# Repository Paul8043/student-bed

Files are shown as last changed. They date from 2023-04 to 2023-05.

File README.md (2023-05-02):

# Student-Bed

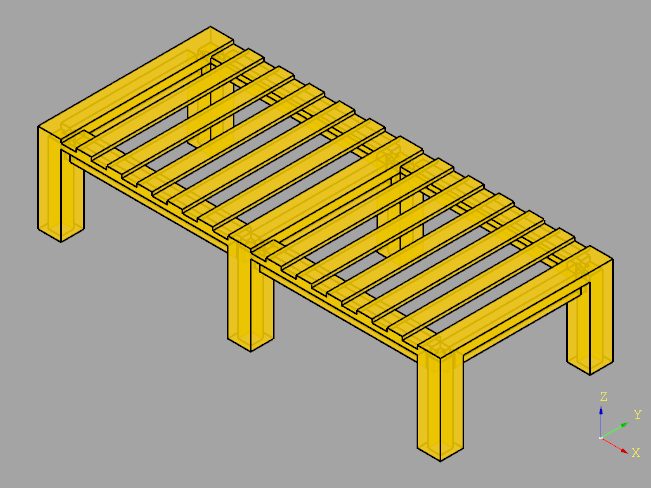
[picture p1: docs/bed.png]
appetizer


# Preamble

Why does this repository exist? My son has declared some demand for an additional bed for his student digs. I have got an order to run a project. That's clear, I take this challenge. This is a perfect candidate to learn Python, Cadquery and some aspects of Woodworking. The entire project is organized as a sequence of mile-stones. After each mile-stone I will add an entry in this Readme.md. Stay curious, I will take you along for a longer, and hopeful, interesting journey. Let us start, the adventure begins ...

# Mile-Stone #1: Model Specification

Before a journey starts, it is always good to know, which destination we want to reach. A clear view of the goal is always helpful. In our case this is a bed, and this bed needs a specification. It comes in two flavors.

The External-Model-Specification, for short EMS, describes the requirements from the view of the customer (my son). Here, he describes what he wants to get. The most important topics are related to measures. All these details can be found in [EMS](docs/EMS.txt). 
 
The Internal-Model-Specification, for short IMS, covers the aspects of the design and implementation. It holds all the details from the view of a cabinetmaker (that's my role). This document can be found here [IMS](docs/IMS.md).

# Mile-Stone #2: Software-Tools 

This project requires some resources for its execution. Some tools are need for the design of the bed, and some others for the wood-working. This project is designed as a tutorial, we try to use the up-to-date tools. Before we do any woodworking, we create a CAD-model first, then we are able to see how it will look like. The tool for this purpose is "CadQuery", a CAD-library written in Python. 

The hidden agenda is to give some stimulus to learn new tools, this applies for us both, for my son and me. Normally 3D-models are drawn by a CAD-Tool. Such tools are powerful, but they require some kind of training. With this project we go in another direction, instead of drawing lines and faces, the 3D-model is programmed, that means we have to write a python-program. This strategy has some advantages, the python-program is very compact and easy to maintain. Changing measures are only a few clicks away.

How does this work? How to convert a python-program to a visual 3D-object? This is the task of a 3D-viewer (renderer), in our case this done by CQ-editor. "CadQuery" and "CQ-Editor" are close companions. In most cases they are used together. As the naming might indicate, the "CQ-editor" can do more than visualizing the model, it has also some capabilities to adapt the python-code. It is a small IDE (Integrated Development Environment). For our purposes this IDE is fully sufficient.
 
As always, a running project is never a straight forward going. It is more an evaluation of various alternatives. Going back and forth is quite normal. What might be the best solution, that will crystallize out later during our journey. Because of that it makes a lot of sense to have good revision-control-system, which can store all intermediate revisions. The top-candidate for this purpose is "git".

And because now-a-days everything can go to a cloud, we establish the infrastructure for this, too. Here we choose GitHub, a platform where you can host your public projects for free. Git and GitHub are also close companions. All code for this project is kept in a folder on the local machine. With some git-commands this folder can be transfered to GitHub and vice versa. In the name-space of GitHub this folder is called a "repository".

There is one thing left over. What kind of editor we will use, for modifying our source-files? We could do this with CQ-Editor, but for this scenario we choose VS-Code. At first glance it looks like an another editor. That's true, but it has many benefits (will become clearer soon).
 
So far, the tool-box for the software-side is almost complete. What is needed for wood-working will be discussed later.

# Mile-Stone #3: Risks with Software Installations

On the windows-platform performing installations is coupled with some risks.

Such a task can be accomplished in a few minutes, if you have good and proven recipe (good luck). If you don't have one, calculate more time, it can consume hours, days, weeks or even more (bad luck).

The standard procedure is:
* go to the web-page of the application
* download the package for your platform (in our case windows)
* read the install-instructions
* run the installer by double-clicking
* answer the questions that the installer might ask

If you fetch the application from an app-store, these steps may run unter the hood. This looks feasible. Normally the installation-instructions are described from the perspective of a blank windows and me-alone-application. But this is an unusual case!

Scenario 1: blank windows + me alone + defaults only (no risk)

This is easy doing. Do not expect any problems.

Scenario 2: blank windows + me alone + defaults changed (low to medium risk)

The installer might ask several questions. Sometimes it is difficult to give initially the right answer, because it is not clear what kind of consequences are associated with your choice. Good written applications offer later on the possibility to adjust these parameters. But most applications give you only a single chance, as long as the installer runs. In this case the installation has to be re-run, by calling first the de-installer. In most cases the de-installer does only remove app-code, but not the associated settings. If you try to re-run the app again, very often you see the same trouble as before. You have to consult "stackoverflow" to see whether there is a solution available. The settings can be scattered all over the world. Try to inspect the dot-files inside your home-directory, your AppData-tree, and sometimes the registry needs special care. At any case to get rid of old settings is a challenge for its own.

Scenario 3: updated windows + old-me (low to medium risk)

A lot of applications have a built-in updater. Try to use it as first choice. Your settings will be preserved and only the code gets updated. This has low risk. If you have to de-install first, then the risk will rise up to medium level.

Scenario 4: updated windows + many other apps + me (high risk)

Typically an application does not only depend on windows, but on some other applications. And each application can request specific revisions of other applications. This is really a difficult scenario, which means the applications have to be installed in the right sequence. And sometimes the applications request contradictory revisions.

Scenario 5: broken installation (highest risk)

An installation should always be an all-or-nothing operation, which means an application should succeed or leave the computer untouched. On the windows-platform installations are something in between. This situation can be reached easily, if the installer fails. In this case the application is in a corrupted state. It is like a zombie. You can only recover by applying steamroller tactics which means installing windows from scratch, waiting for days until all window-upates are applied, and installing all other applications again!

To make this long story short: Make sure you have a backup of at least your user-data, or even better, create an image-backup first to preserve your working environment!

# Mile-Stone #4: Software Installation

Our installations belong to scenario 4, which means we are walking in the high risk area.

The following procedure describes the needed steps, assuming that these applications are currently not installed on your computer. If some are already present, you can skip individual steps. But be aware you are entering an unexplored area which may show up new surprises.

Make sure that your windows is up-to-date (windows-update).

We install "git" first. Follow the instructions given [here](docs/HowTo-Git.txt). The video there, is highly recommeded. Don't forget to specify "user.name" and "user.email" at the end of the procedure. Without that "git" will reject to perfom any work for you. If it succeeds, you will have a Git-Bash on your desktop. With this you can open a Command-Shell. It looks similiar like a CMD-window, but is offers much more capabilities. You get full access to "git" and some famous linux tools like "find" and "grep". Always use the Git-Bash, if you plan to talk to "git" from the command-line level. Other Command-Windows like CMD or Power-Shell do not have the right context. Keep that in mind.

Next we take care for GitHub. GitHub promotes "GitHub Desktop". It is not really needed for our initial steps. Do not install it at this point. To use GitHub, you don't need any installations, you need just an account. Perform the steps listed [here](docs/HowTo-GitHub.txt). Then define your first "repository" which consists initially of 3 files: a "Readme.md", "LICENSE" and a ".gitignore". For ".gitignore" select the template for python. The "LICENSE" is up to you. There is one subtlety here: "git" had asked you to specify your email-address and "GitHub" has asked you for a login-name which is likewise also an email-address. Both work only work smoothly together, if the email-address is same for both.

The next application is Visual Studio Code, often simply called VS-Code. Originally it has been designed as an editor. But in the meantime it has reached the level of a comfortable IDE (integrated develop environment). VS-Code has extensions for almost everything. For Python and many other programming languages. Besides this, it offers built-in git-support. By using VS-Code you can do all needed git-tasks thru the graphical interface which is really simple to use. Some more details are given [here](docs/HowTo-VSCode.txt)

The welcome-screen, which pops up during first start-up, recommends some other things to activate. Be reserved and resist the temptation to activate more. If I remember correctly, there was one flag related to git, which I have activated.

You should only install the following extensions for the very beginning:

* Your language Pack
* Git Graph
* Python (by Microsoft)

Now we have reached a stage where we can consider to install CadQuery and CQ-editor, see [here](docs/HowTo-CadQuery.txt) to grasp all the details. And as always, goto the web-page and learn how to install. After you have read the Readme.md, you are overwhelmed by such a variety of choices. And what does fit for my machine? The first answer is, it depends: great! You have come in touch with new tools never heard before. Some phobia came up in my head, because this looks like additional work. There will be more effort needed to get the new serpents, called "conda" and "mamba", under control. They don't have an own home, they reside together in a common refugium called [miniforge](https://github.com/conda-forge/miniforge).

It will take awhile to find out how the things work in this area. You know already, all this stuff belongs somehow to python-installations. A lot of strange things at first glance. The goal is to find a running combination of Python, CadQuery and CQ-Editor. All 3 depend on other packages, and each of them can have additional dependencies. Python has a package-manager called "pip". Why is "pip" not sufficient? And then you remember why some installations are associated with high risks (scenario 4). Because they might have contradictory requirements. Could "conda" and "mamba" be a solution for this problem? We will see it soon. In this context a new term, named "virtual environment", appears on the scene. Unfortunately there exist several flavors of "virtual environments" and which is the right one for my project? Questions over questions. There is no other way as to learn these tools. Thanks to the internet you get access to this information immediately, but it takes time to learn. So, my first model, created by CadQuery, has to wait.

And it would make sense to check how big is already the chaos on my computer? How many different versions of python can I find? A double-click on a python-script opens Thonny. Luckily Thonny comes with a built-in version of python and any pips remain in the conext of Thonny. This is good so far. But I can do "python --version" in various Command-Windows. Some do not see Python at all, some others show older versions. Not so nice! Then I found an old Anaconda installation, which I have removed by calling its de-installer. Thonny, I want to keep. I hope the field is cleared enough and ready for CadQuery.

To make it clear:
* pip is a package-manager only
* conda is a combination of environment-manager and package-manager
* mamba is simply a faster conda

The environment-manager creates the needed virtual-environment. This is some kind of a sand-box for your application and the needed dependencies.

The contours got shaped, the picture is clear enough to start. This means I will continue with "mamba".

Let us try to install mamba. All details are given [here](docs/HowTo-Mamba.txt)

After this little detour we return back to the installation of [CadQuery](docs/HowTo-CadQuery.txt). The installation is more or less a one-liner!

Now it is time for a longer coffee-break!

# Mile-Stone #5: Say Hello

Whenever a new environment has been set up, it is good practice to check, whether all tools are callable. For this purpose we say [hello to python](docs/hello-python.py). This is just an one-liner, a simple print-statement. We try this first on VS-Code. Make sure that the python-extension has been activated, then run the program. In the lower panel there is a tab, named Terminal, where you can find "Hello, Python" among some other text. Now we do the same thing with CQ-Editor. The one-liner appears in the Editior-Panel, but pressing the run-icon does not show any reaction, the console-panel at the bottom remains empty. This is unexpected behavior. Reading again the Readme.md of CQ-Editor reveals the output does not go to the console-panel, but it appears on the shell-window, from where the cq-editor has been started. Not very comfortable, but there is offered a better alternative named log().

Now we say [hello-to-cadquery](docs/hello-cadquery.py). With VS-Code the python-program runs without any complaints, but there is no graphical output. This is expected behavior, because nothing is built in the code to show graphics. Now we try the same thing with CQ-Editor. And oh wonder the model appears on the right upper corner. The CQ-Editor can show models without any lines of code. This is great.

But then why writing a section in the Readme.md which explains how to create graphical output, if it works without? There you can learn, only 2 functions are in charge with graphical output:

* show_object()
* debug()

Uncomment lines #6 to #9 and see what happens. The top-face is colored red, and logger-output appears in the Log-Viewer in the lower-bottom corner. Both functions are only needed, if the graphical output has to be customized in some way. Now we make the cross-check on VS-Code and we see some dark clouds at the horizon, because it reports several errors. VS-Code does not know show_result(), debug() and log().

# Mile-Stone #6: Template for Both

Some stubs are created, so that the python-script can be run without any errors on both editors. The template is given [here](docs/template.py).

# Mile-Stone #7: Recommended Workflow

There are many variants possible. The sequence below is easy to use for newbies.

1) create a repository on GitHub
2) clone it to your local machine
3) take the template from the docs-directory as a skeleton to start with
4) activate environment via mamba
5) start VS-Code & load your folder
6) start CQ-Editor and load your python-program
7) edit & modify your program, SQ-Editor will draw the model after every change
8) commit your changes to git, and optionally to GitHub
9) repeat steps 7 to 8 
10) close CQ-Editor
11) close VS-Code
12) deactivate environment via mamba

If the repository is created first on GitHub, this has the advantage that the relationship between "remote" and "local" is established from the very beginning.

Some additional hints to "git". The git-database, which holds all your revisions, is stored in a hidden folder named ".git" and it is stored in your project-directory. Never touch this folder and its contents, it would lead to a corrupt database, and all your version can disappear. Having ".git" directly under your project-directory implies that when the project-folder is moved, all revisions go along automatically. There is another dot-file, named ".gitignore". It controls which files and sub-folders are put into ".git". Files and sub-folders excluded here, remain untouched by git, they are untracked. These files and folders can resides anywhere in your project-tree. They remain untouched. They will never appear on GitHub. Keep in mind, "git" has been designed for processing text-files, not for binaries. Binaries can be added, but they consume a lot of space. For each change a copy of the binary is added. Because of that do not store large binary files (BLOBs). The repository will grow quickly and uploads & downloads will take very long.

Steps 7 & 8 need some more explanation. "edit" and "save" are clear. Revision-handling with git is a 3-step-approach: 
* add a file, after saving, to the stage-area. A file there is marked with "A".
* make a commit, the contents of the stage-area goes to the ".git"-folder
* press synchronize, this works in both directions, after that the local changes appear on GitHub.

The CQ-Editor is primarily used as a model-viewer. In the View-menu turn off all unwanted panels, except "Log viewer" and "Current traceback". And in the Preference-Section enable "autoreload". This flag is required, otherwise an automated model-refresh does not take place, if the model has been changed with VS-Code.

# Mile-Stone #8: Let the Model grow

The design is kept simple. The duckboard is split into 2 halves (not visible at the moment). In total we need only 4 different parts:
* jambs 
* stringers
* ledgers
* battens

[parts-piled-up](docs/bed-piled-up.jpg)

A jamb has a hollow body. The ribs can be plugged into the slots of the jamb.

[jamb](docs/jamb.png)
[rib](docs/rib.png)

The frame is built with 6 jambs and 7 ribs.

[frame](docs/frame.png)

The duckboard covers only one half of the bed. The battens are simply loaded on top of the stringers and ledgers.

[stringer](docs/stringer.png)
[ledger](docs/ledger.png)
[duckboard](docs/duckboard.png)

Both duckboards are loaded on top of the frame and the bed is ready. Mission complete, at least related to the design.

[bed](docs/bed.png)

# Mile-Stone #9: Prototyp

CAD-Model are great, but the real thing is better. Why not print the model with a 3D-Printer? The jambs can be printed in their original orientation. The ribs are flipped by 90 degrees and the duckboards are printed upside-down.

Simply, puzzle the parts together and the prototype is ready.

[prototype](docs/prototyp.jpg)

# Mile-Stone #10: Storage Check

The bed is demountable. Just open the screws on top of the jambs. All parts can be stacked together. They fit easily in the stoarage area, specified in the [EMS](docs/EMS.txt)).

[parts-stacked](docs/bed-stacked.jpg)

# Mile-Stone #11: Bill Of Material

It is time to order material. The complete list given as CSV-File, see [bom](docs/bom.csv).

# Mile-Stone #12: Generation of SVG-Files

With the 3D-model ready, it should be a simple task to generate the SVG-files. But this was not true.

The generation of SVG-files was more difficult than expected. The original idea was to make some sectional views of the needed parts. My router expects SVG-files and CadQuery can generate SVG-files and many other formats. This works in principle, however there are two limitations:
1) A simple sectional view is not enough for the router. Some helper-lines are needed, which have to be added.
2) CadQuery puts a projection of the 3D-model into the SVG-file.
The projection can be switched off, but the output is scaled to some unknown factor. This ok, if the SVG-file is just used as a viewer, but for my purpose (to control directly the router) this does not fit.

Because of that, the initial idea has been given up. The 2D-drawings are created as additional entities. They are stored in DXF-format. QCAD is used for the post-processing, close polylines, set the map scale to 1:1000 and increase the line width to 0.13mm (ISO) and then do an extended SVG-Export

In total 4 SVG-Files are needed. The jamb is assembled of 2 broad and 2 small sides.

jamb-broad

jamb-small

It is always difficult to drill holes in abutting faces. The jig below helps to do this.

jamb-jig

And the ribs need both-sided notches.

rib-short

# Mile-Stone #13: Implementation

The model does not show all details. The prototype generated by the 3D-printer has some special requirements, and this may deviate from the wooden realization. All the aspects, how the wooden parts are joined together are not covered in the model. These are decisions of the implementation and the issues in this area are described in the [IMS](docs/IMS.md). The bed is a simple construction and therefore the IMS can be kept short. Only a few things need to be discussed there. The frame, consisting of jambs and ribs, does not need any kind of special junction-elements. The notches in the wood are sufficient. For the duckboard it looks different. The bed has to be demountable and because of this some screws are a good and simple solution. I have chosen screws with metrical threads and these screws need a metallic counterpart, called inserts. This gives a very stable junction, which can be easily detached. The leftover is normal wood-working. The focus here is, how the wooden parts can be routed easily. This depends on the equipment, you can use. The drawings for routing are already covered in the previous mile-stone.

After so much work we can have a look at the real bed!

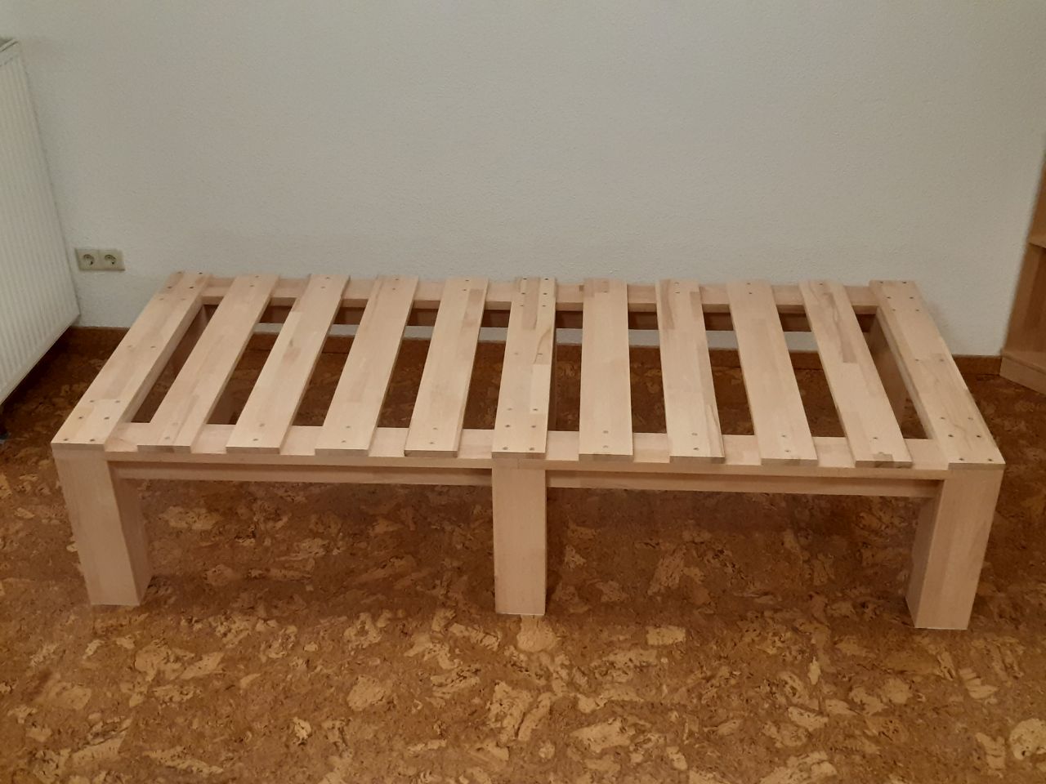
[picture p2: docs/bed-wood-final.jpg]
bed-wood-final


# Mile-Stone #14: Delivery

The delivery has already taken place. The transport was easy and the mounting of the bed was simple, too. The setting-up time was 25 minutes, a few minutes more than expected!

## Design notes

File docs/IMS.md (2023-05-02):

Internal Model Specification

This document describes how the bed is built up. 

The main focus here is how the wooden parts are made and how they are joined together. For the frame the notches serve for this purpose. Jambs and ribs can be simply plugged into each other. For the duckboard it looks different, here the junctions are made with screws. The duckboard consists of two halves. They have to be connected with each other and both with the frame. In the corners the duckboard is bolted with 4 screws. In the middle the duckboard is only bolted with 2 screws. So, the jamb in the middle, with its 4 inserts, is shared by both duckboards and the batten on top belongs to both duckboards. This gives a stable connection and the optical appearance is pleasing.

The bed has to be demountable and because of this woodscrews would be a poor choice, it is much better to use screws with metrical threads. The screws need a metallic counterpart as a nut. But normal nuts would also not be a good choice, better to use inserts, they will remain all the time in the wood, they cannot get lost.

Now, let us go back to the wooden parts. We need pre-cut-plans for all oft them. The dimensions are listed in the [bom](bom.csv).
 
Some wooden parts deviate from the plastic-version of the prototyp. There the jambs are a single box which is shelled out. The wooden-version consists of 2 broad and 2 small sides which are glued together later on. This is mentioned, because the pre-cut-plans show parts which cannot be found in the model.

In our do-it-yourself-stores glued beech wood is offered with thickness of 18mm and 27mm. The format for 18mm is 200cm x 40cm and for 27mm the format is 260cm x 63.5cm. These plates are taken as raw material. The following pre-cut-plans show how the individual parts are cut-out.

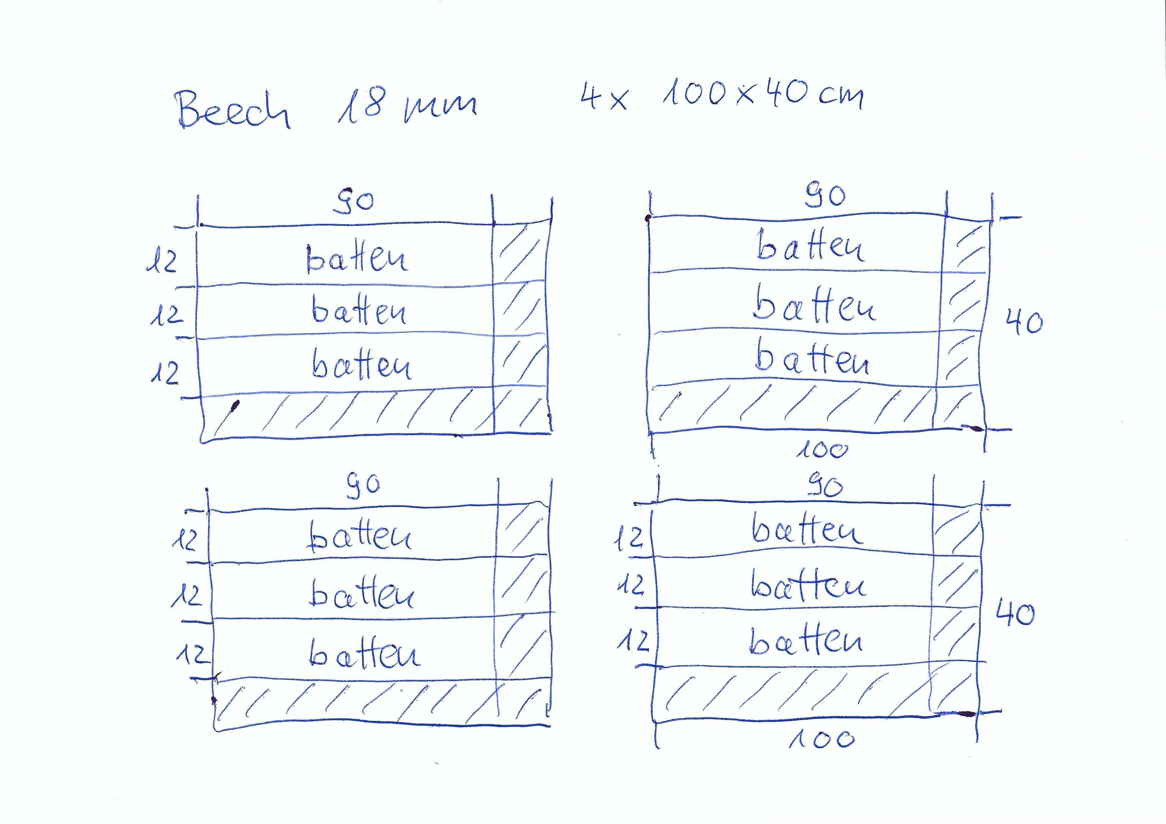
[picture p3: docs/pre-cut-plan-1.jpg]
pre-cut-plan-1


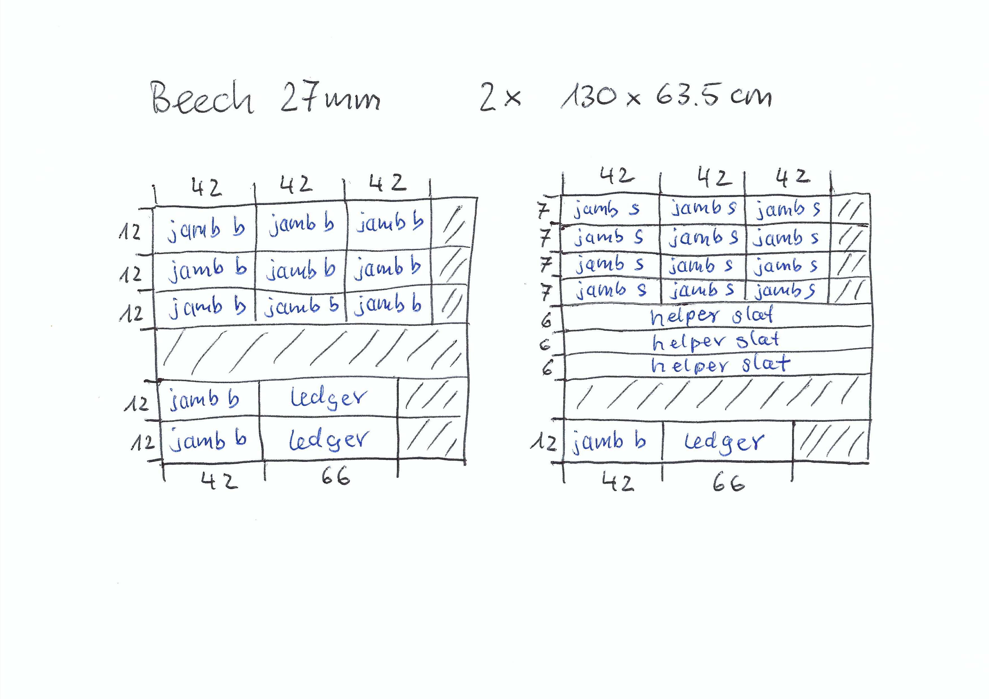
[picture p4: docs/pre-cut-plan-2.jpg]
pre-cut-plan-2


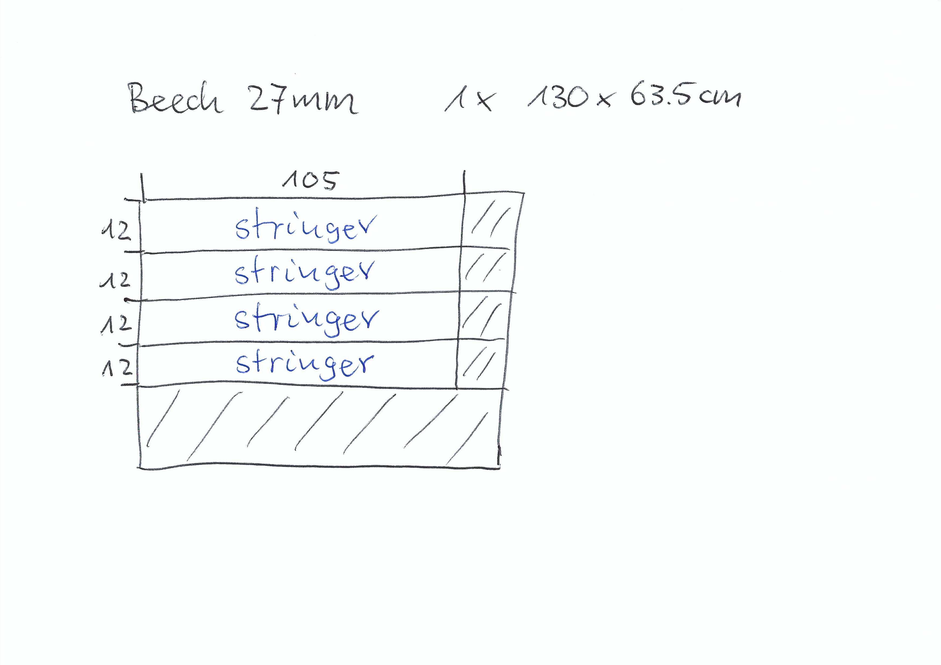
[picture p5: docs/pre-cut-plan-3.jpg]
pre-cut-plan-3


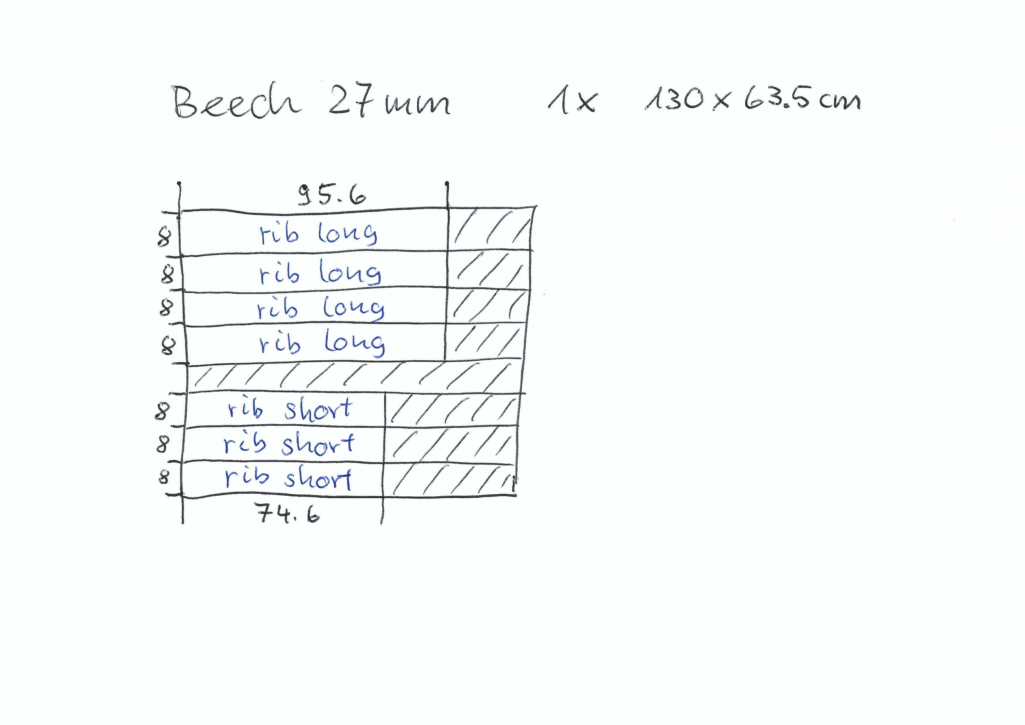
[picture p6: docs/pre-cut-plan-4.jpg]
pre-cut-plan-4


The next step is to make cut-outs of the jamb-plates. This is done with the help of two 2D-drawings:

jamb-broad

jamb-small

The inner rectangle shows the nominal size of the plate. The outer rectangle is 10mm larger on all sides. This helps to mount the plate for the router. The cut-out-area, also a rectangle, is extended by 5mm on the left side. This needed to get a straight line, otherwise the milling-cutter (6mm) would make a fillet.

The jamb, if glued together, looks quite well.

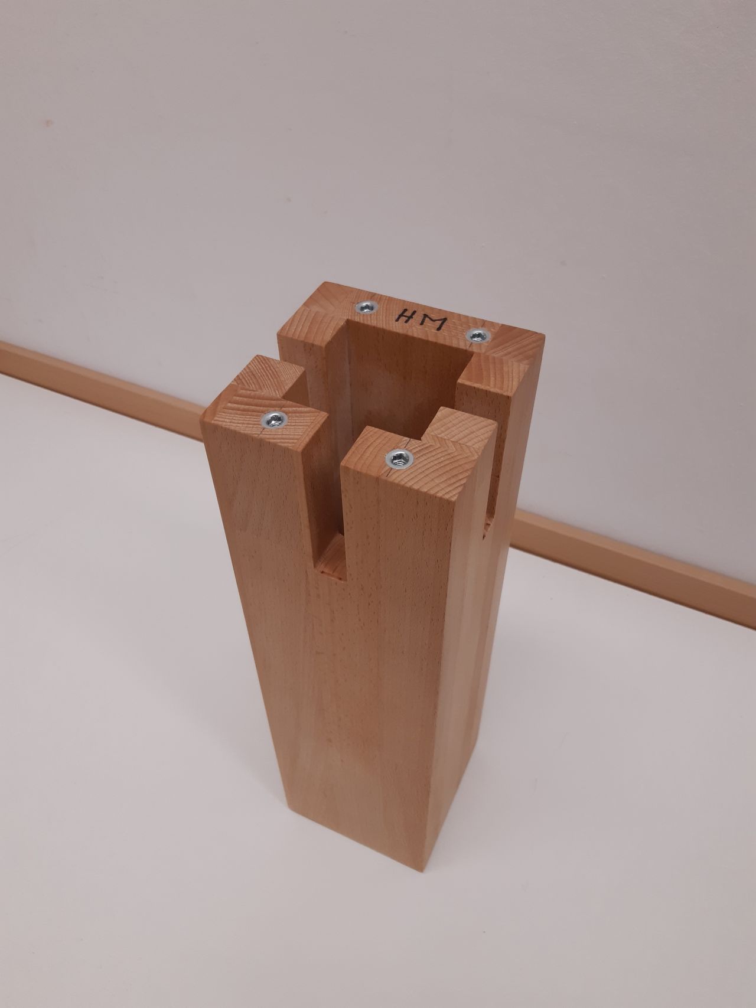
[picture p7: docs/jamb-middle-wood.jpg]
jamb-middle-wood


The drilling of the holes for the inserts is not trivial. They have to be positioned very exactly and the holes have to be perpendicular. The size of the jamb is too large for a standard drilling-machine. There was no other choice as to try a free hand drilling. And, that this will be successful, I made a jig for this purpose. The 2D-drawing for the jig can be seen below.

jamb-jig-qcad

And the wooden version looks this way.

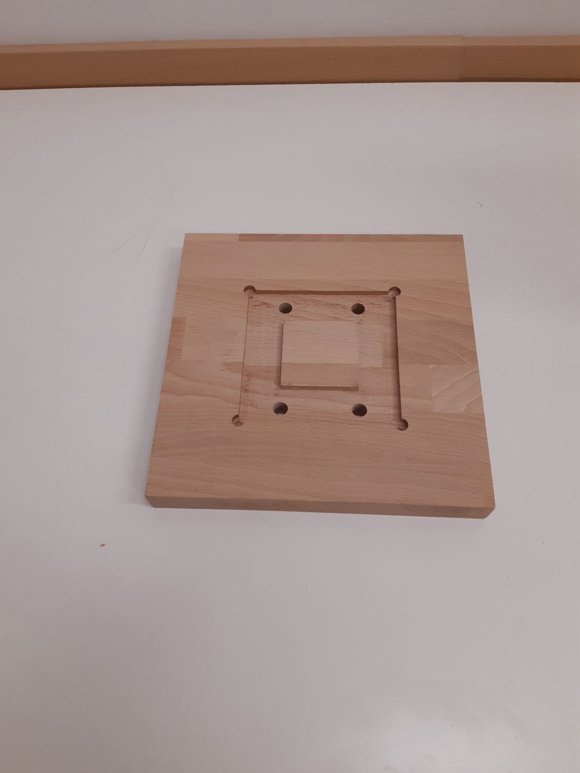
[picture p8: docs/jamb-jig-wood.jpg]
jamb-jig-wood


The jig is simply put on the top of the jamb, but upside down. Then the drill-bit has enough leading and hole is really perpendicular.

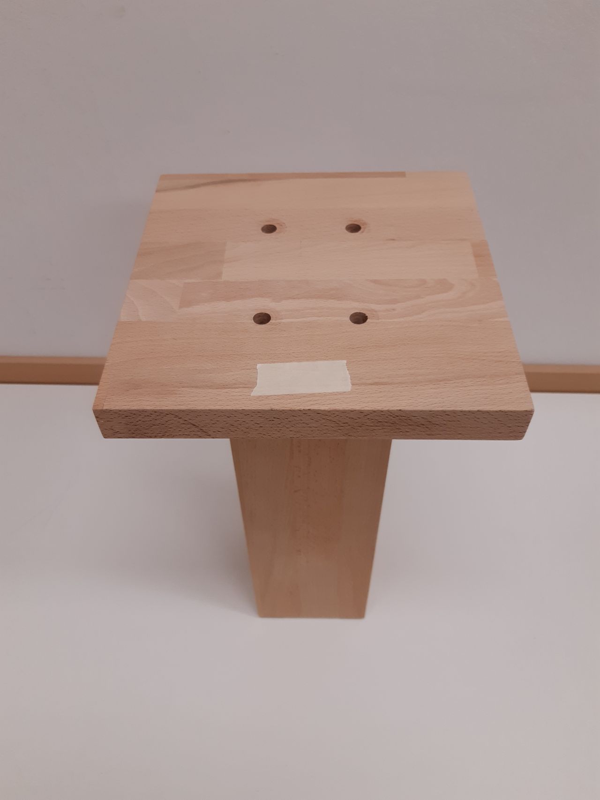
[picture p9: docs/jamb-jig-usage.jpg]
jamb-jig-usage


The holes for the remaining parts are uncritical, the are drilled on a drill press.

And as always, some not planed problems occur. Two of the stringers had ugly knotholes.

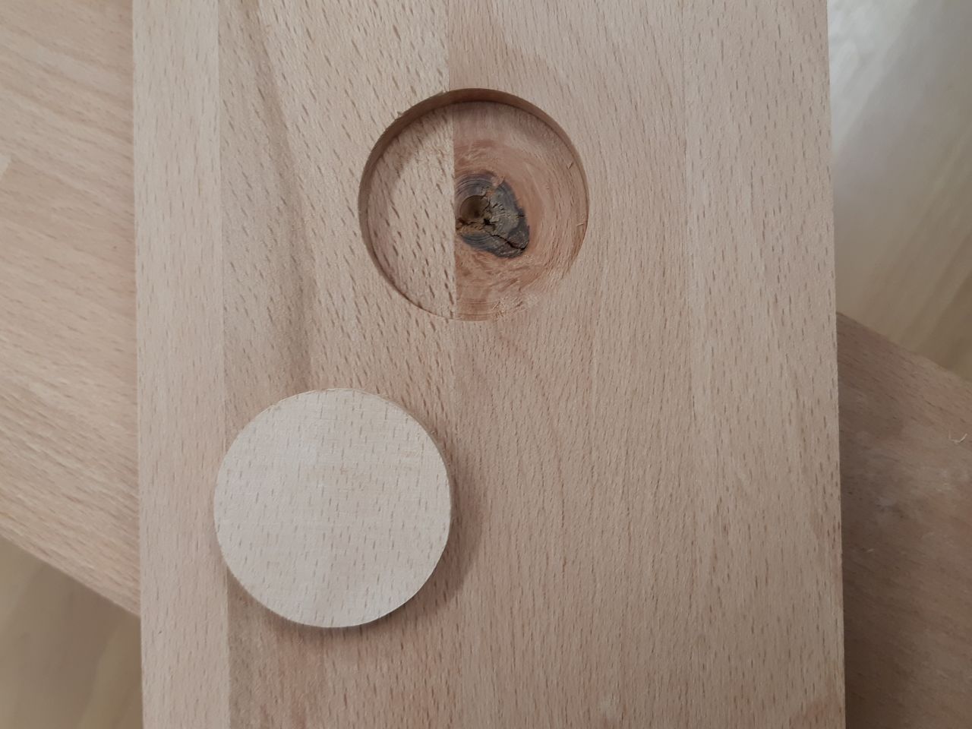
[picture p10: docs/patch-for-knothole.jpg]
knothole


After the repair it looks much better.

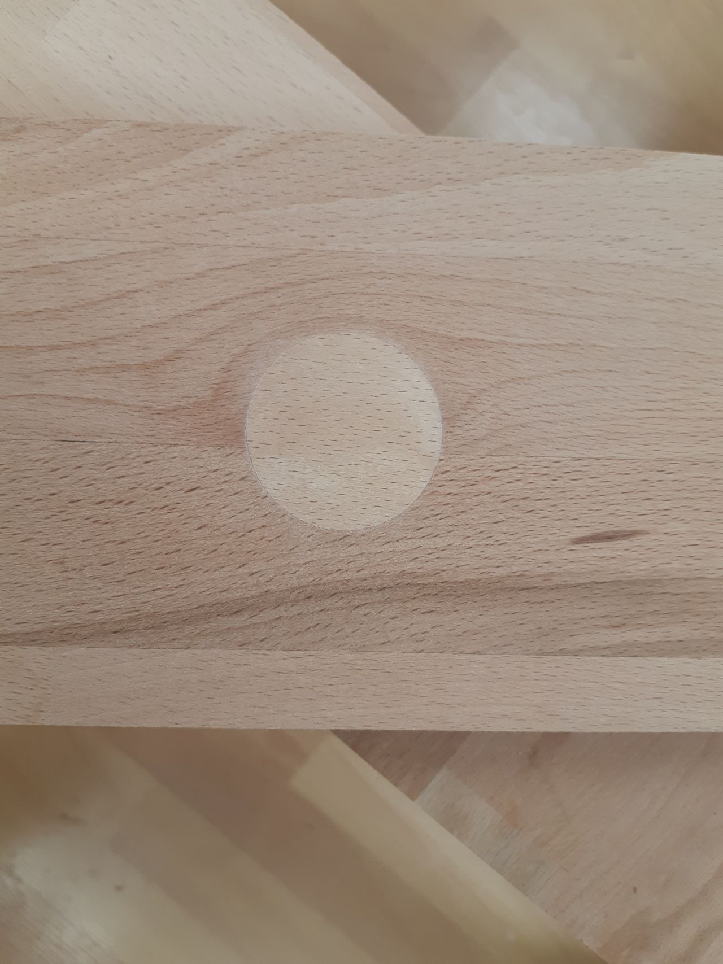
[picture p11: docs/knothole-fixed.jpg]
knothole-fixed


Just for completeness all other wooden parts are listed below.

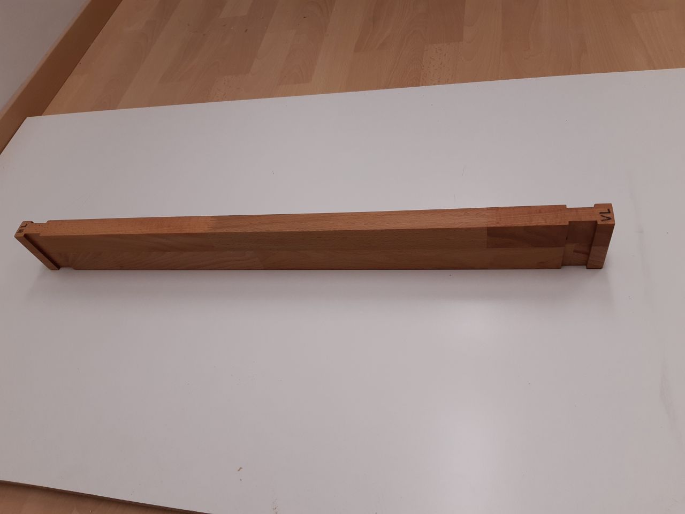
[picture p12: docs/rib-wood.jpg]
rib-wood


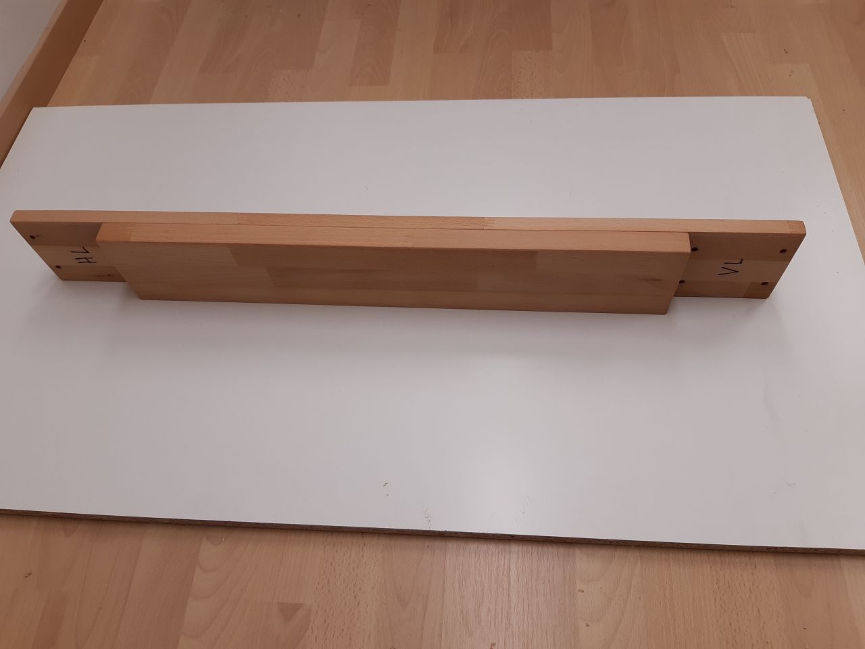
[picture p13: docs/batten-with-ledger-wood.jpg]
batten-wit-ledger-wood


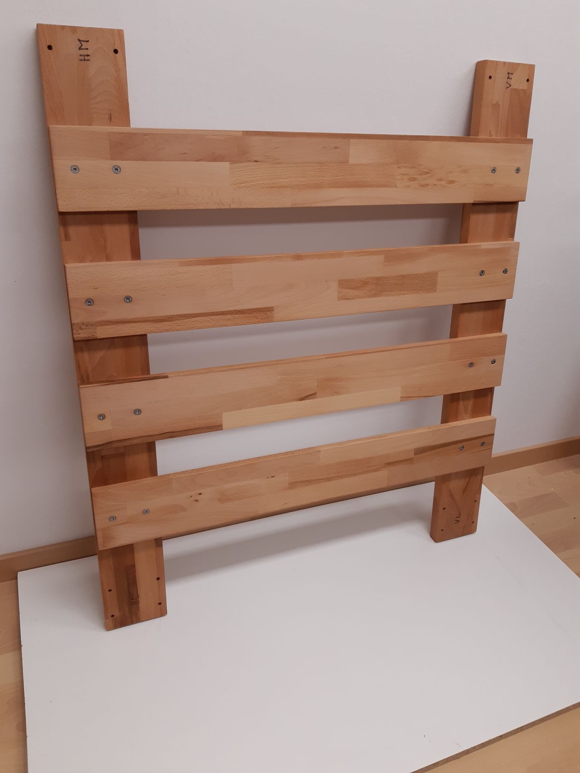
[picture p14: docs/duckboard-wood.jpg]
duckboard-wood


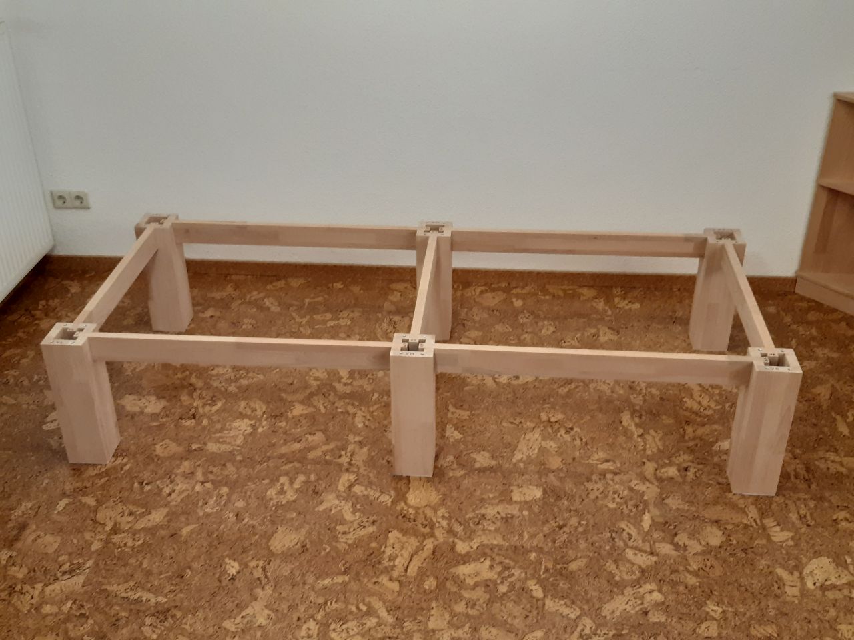
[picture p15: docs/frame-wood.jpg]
frame-wood


And our final result, everything mounted together, looks fine.

bed-wood-final

Mission complete!

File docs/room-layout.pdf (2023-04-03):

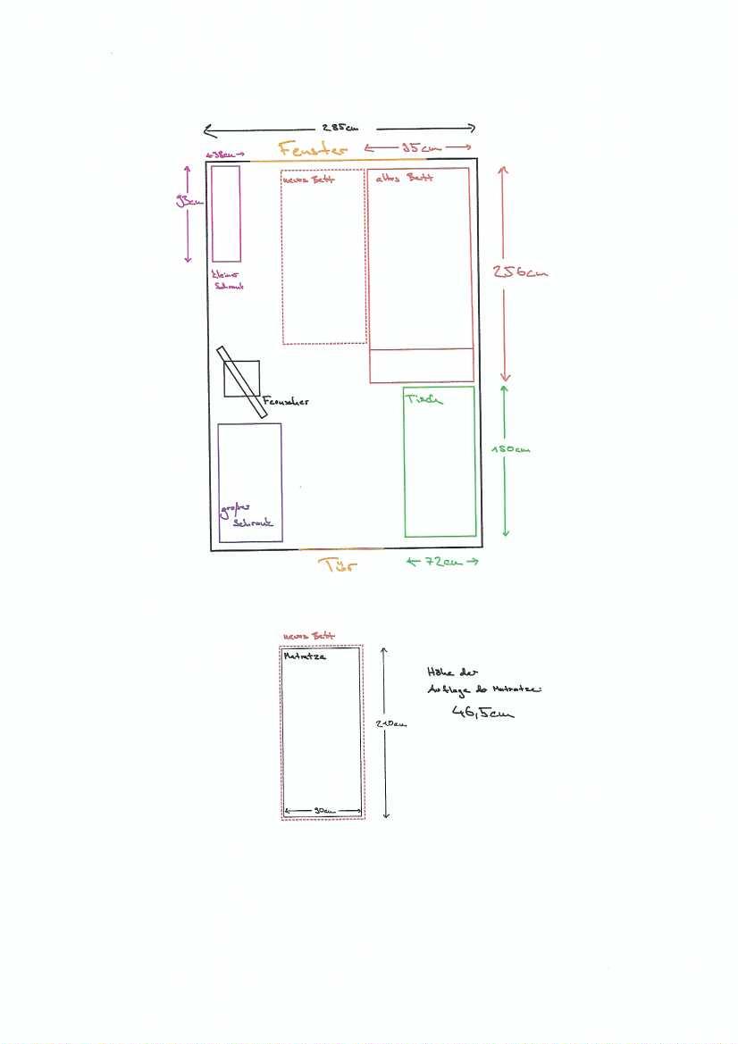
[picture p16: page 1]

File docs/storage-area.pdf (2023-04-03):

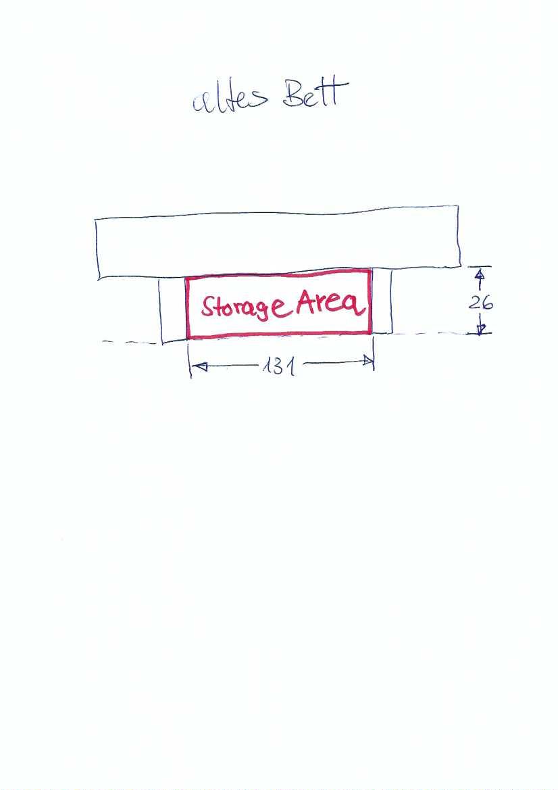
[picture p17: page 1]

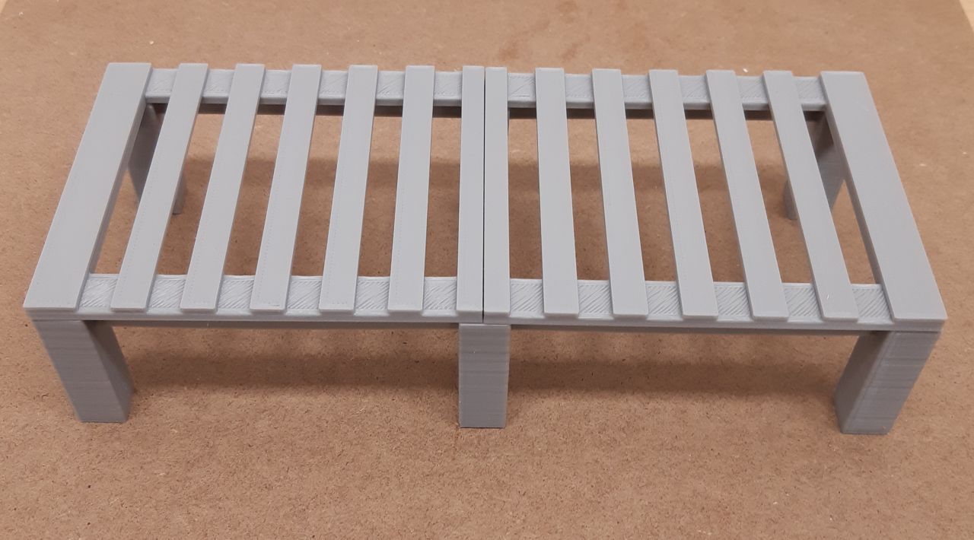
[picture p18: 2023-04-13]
docs/prototyp.jpg

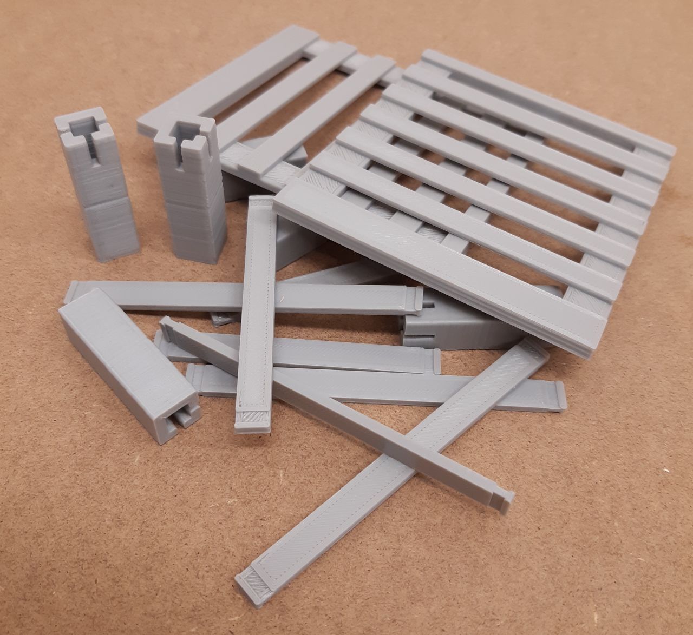
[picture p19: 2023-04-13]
docs/bed-piled-up.jpg

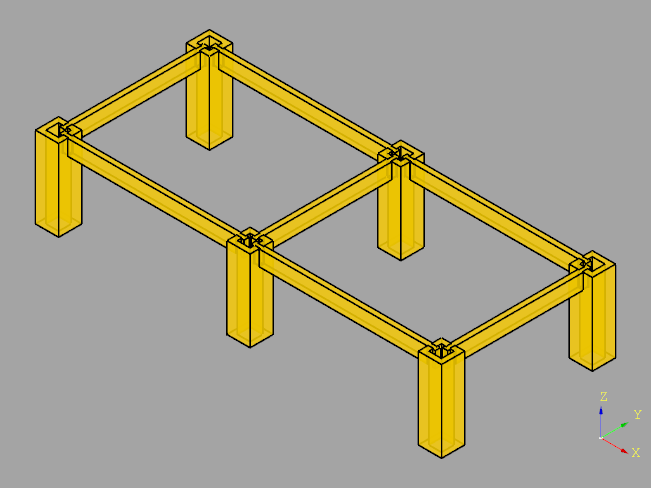
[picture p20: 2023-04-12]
docs/frame.png

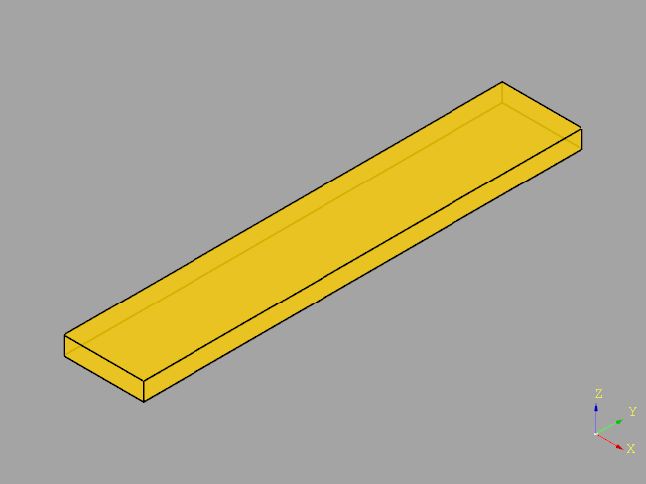
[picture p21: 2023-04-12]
docs/ledger.png

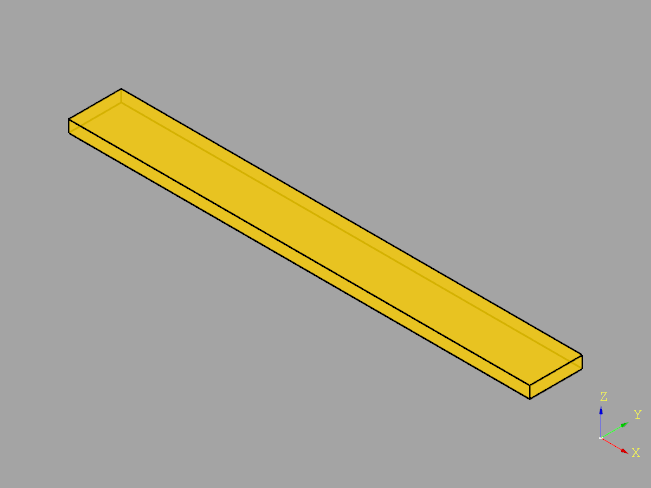
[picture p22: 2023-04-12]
docs/stringer.png

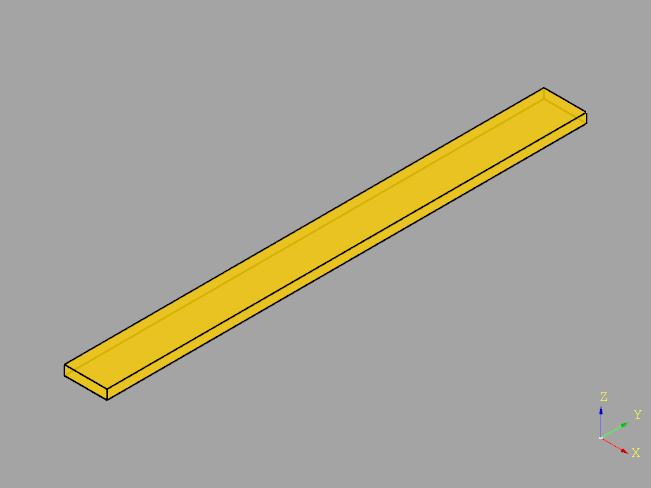
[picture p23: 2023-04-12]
docs/batten.png

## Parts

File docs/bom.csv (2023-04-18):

QTY | REF-DSG | NAME | MATERIAL | DIMENSIONS | MPN | URL
12 | JB | jamb broad | beech | 420 x 120 x 27 |  | diy-store
12 | JS | jamb small | beech | 420 x 66 x 27 |  | diy-store
4 | RL | rib long | beech | 956.0 x 80.0 x 27 |  | diy-store
3 | RS | rib short | beech | 746 x 80.0 x 27 |  | diy-store
4 | S | stringer | beech | 1050.0 x 120 x 27 |  | diy-store
3 | L | ledger | beech | 660 x 120 x 27 |  | diy-store
11 | B | batten | beech | 900 x 120 x 18 |  | diy-store
24 | SL | screw long | steel A2 | M6 x 65 | 1102706065 | www.frantos.com
50 | SS | screw short | steel A2 | M6 x 35 | 1102706035 | www.frantos.com
74 | IS | insert SKD330 | steel zinc plated | M6 x 18 | 420618001 | www.rampa.com

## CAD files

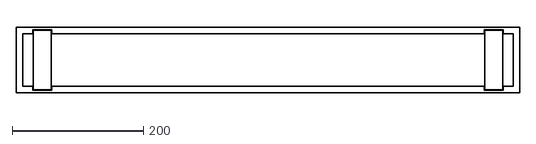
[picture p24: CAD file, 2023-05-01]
docs/rib_short.dxf
766.0 x 100.0

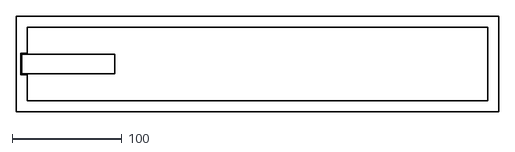
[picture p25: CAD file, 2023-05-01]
docs/jamb_small.dxf
440.0 x 86.8

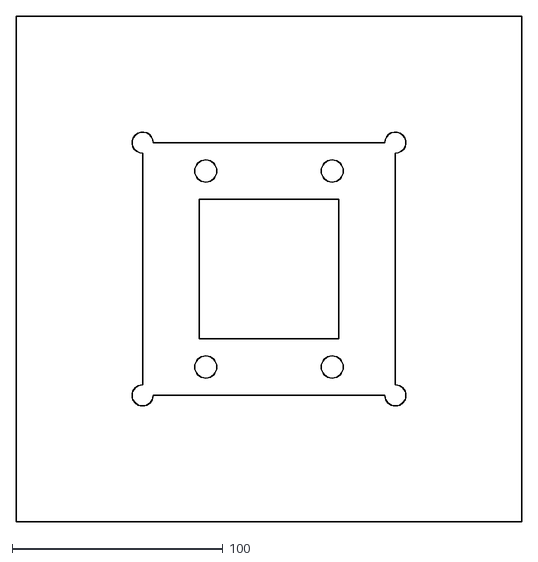
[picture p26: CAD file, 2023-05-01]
docs/jamb_jig.dxf
240.0 x 240.0

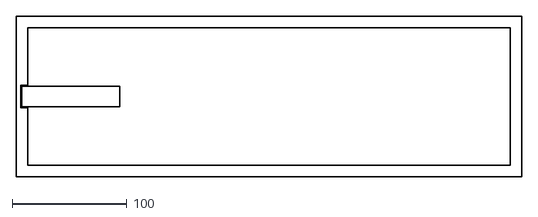
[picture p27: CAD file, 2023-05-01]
docs/jamb_broad.dxf
440.0 x 140.0

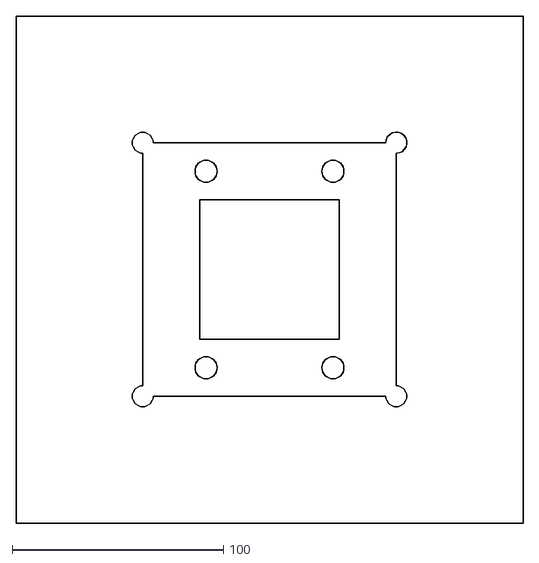
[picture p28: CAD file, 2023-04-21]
docs/jamb_jig_qcad.dxf
240.0 x 240.0

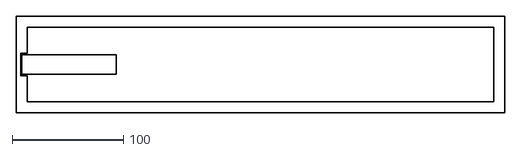
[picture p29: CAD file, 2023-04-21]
docs/jamb_small_qcad.dxf
440.0 x 86.8

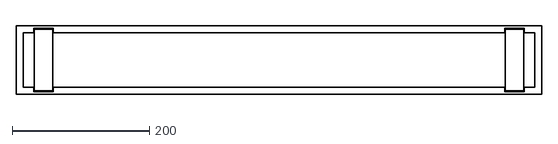
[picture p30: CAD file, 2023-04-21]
docs/rib_short_qcad.dxf
766.0 x 100.0

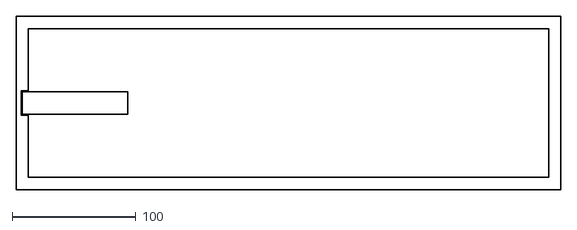
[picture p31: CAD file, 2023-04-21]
docs/jamb_broad_qcad.dxf
440.0 x 140.0

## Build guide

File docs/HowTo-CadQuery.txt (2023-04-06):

HowTo: Installation of CadQuery & CQ-Editor

1. URL
   https://github.com/CadQuery
	 
2. Docu
a) CadQuery:  https://github.com/CadQuery/cadquery
b) CQ-Editor: https://github.com/CadQuery/CQ-editor
Each of them has got an individual installation procedure. But what is the
best way to install both together? Does a "cq-editor=master" also implies
a "cadquery=master"? This is not so clear, at the moment.

3. Creating the "sandbox" for CadQuery
Decribed from a view-point directly after a mamba-installation.
a) mamba env list
   You see only one environment, named "base". It is reserved for mamba,
   Never try to install something to "base".
b) mamba create --name "cqe-env"
   This will create an empty environment for CadQuery.
c) mamba env list
   Now we have 2 lines. But the asterisk still points to "base", which
   means that "base" is the active environment.
d) mamba activate cqe-env
e) mamba env list
   Now the asterisk has moved to "cqe-env". This is the ensvironment that
   we use for our installations.

3. Installation of CadQuery & CQ-Editor
a) make sure that "cqe-env" is active
b) mamba install -c conda-forge -c cadquery python=3.11 cadquery=master cq-editor=master
   "cadquery" appears twice in the command-line. The channels, the name after a -c option
   determines from where the packages should be fetched. In our case we have 2: "conda-forge"
   and "cadquery". The remaining commandline-arguments specify packages, here we have 3:
   "python", "cadquery" and "cq-editor". In principle the specification of only 
   cq-editor=master should be sufficient. This means you get the latest and greatest version
   of "cq-editor". But because it is not so clear, which version for "cadquery" is selected,
   I pin the version for cadquery and say "cadquery=master". Now we will get the latest-and-
   greatest version of both. But it is still unclear, which python version will be used.
   Mamba will figure that out, and very often there are several alternatives left over.
   Hopefully mamba selects the highest possible version. But in this case I also pin
   python to my favorite version by specifying "python=3.11". There is no guarantee that
   this combination can be realized. I got it ...
c) inspect the output of the last command
   There should be no errors. Sometimes they are somewhat hidden in the long output-list.

4. Start CQ-Editor
a) make sure that "cqe-env" is active. (should be the case from the last step)
b) cq-editor -h
   This should show the help of cq-editor.

5. Work Done
a) make sure that "cqe-env" is active.
b) mamba deactivate
c) mamba env list         # only as confirmation

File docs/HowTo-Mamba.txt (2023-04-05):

HowTo: Installation of Mamba

1. URL 
   https://github.com/conda-forge/miniforge

2. Docs
a) https://mamba.readthedocs.io/en/latest                                     # mamba doc
b) https://docs.conda.io/projects/conda/en/stable/user-guide/index.html       # conda user-guide
c) https://docs.conda.io/projects/conda/en/stable/user-guide/cheatsheet.html  # conda cheat-sheet
   remember to replace "conda" by "mamba"

3. Download
a) visite https://github.com/conda-forge/miniforge
b) go to the section mambaforge and take the windows version
c) double-click on Mambaforge-Windows-x86_64.exe 

4. What you have got
a) a desktop icon called "Condaforge Prompt"
   replace the title by "Mambaforge Prompt"
b) mamba lives in its own environment called "base"
   it is just used to run the mamba-commands
   leave the "base"-environment untouched, it is for mamba only
c) create additional environments for your application(s)

5. Usage
a) double-click on the "Mambaforge Prompt"
b) activate the desired environment
c) do you work in this "sand-box"
d) deactivate environment

6. Never Never
a) do not deactivate the "base"-environment

7. Additional Information
a) Mamba has a few commands on top of conda. The repoquery-command shows a lot
   of interesting information.

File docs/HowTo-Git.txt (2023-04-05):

HowTo: Installation of Git

1. URL
   https://git-scm.com
	 
2. Docu
   https://git-scm.com/doc
   https://git-scm.com/book/en/v2                # Git Bible
   https://www.youtube.com/watch?v=MgnRFZJ7M2s   # Git Tutorial Deutsch #1 Was ist Git?
   https://www.youtube.com/watch?v=0PWEG6D2MVQ   # Git Tutorial Deutsch #2 Installation und Einrichtung von Git
   https://www.youtube.com/watch?v=AT0jf_qqggs   # Git Tutorial Deutsch #3 Die Grundlagen der Git Bash Kommandozeile
   https://www.youtube.com/watch?v=6oMBdv2rvDA   # Git Tutorial Deutsch #4 - Git Init und Git Commit
   https://www.youtube.com/watch?v=0138WZebblE   # Git Tutorial Deutsch #5 - Git Checkout und HEAD
	 
3. Windows
a) Download: https://git-scm.com/download/win
b) double click on Git-2.40.0-64-bit.exe
c) follow "Git Tutorial Deutsch #2"
d) open the Git-Bash
e) git --version                                # only as a checks

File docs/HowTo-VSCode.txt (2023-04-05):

HowTo: Installation and Setup of VS-Code

1. URL 
   https://code.visualstudio.com
   
2. Docs
a) read https://code.visualstudio.com/docs  - Overview
b) read https://code.visualstudio.com/docs  - SETUP
c) read https://code.visualstudio.com/docs  - GET STARTED
d) read https://code.visualstudio.com/docs  - USER GUIDE
e) read https://code.visualstudio.com/docs  - SOURCE CONTROL
f) read https://code.visualstudio.com/docs/sourcecontrol/overview#_vs-code-as-git-editor
   do it later and only if really needed

3. Installation
a) download for Windows from https://code.visualstudio.com
b) choose Windows x64 User Installer  
c) double click on VSCodeUserSetup-x64-1.77.0.exe

4. Customization
a) The initial welcome-screen offers a plenty-list of possibilities. Flag only git-support,
   nothing else, at least for the moment.

5. Extensions
a) Your language Pack
b) Git Graph
c) Python (by Microsoft)

5. Notes
a) The de-installer of VS-Code removes only code, but preserves any kind of settings.
   If you have to re-do the installation, then perform first:
   C:\Users\Paul\.vscode in your home-directory
   C:\Users\Paul\AppData\Roaming\Code

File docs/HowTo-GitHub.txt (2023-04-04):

HowTo: Setup a GitHub-Account

1. URL 
   https://github.com
   
2. Setup Login
a) email-address must match with the value of "user.email" from git-installation

3. Setup a Repository
a) Readme.md     # short description
b) LICENSE       # select from the pull-down-menu
c) .gitignore    # select the template for python

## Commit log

2023-04-08 complete bed
2023-04-08 show bed
2023-04-15 measures tweaked for 3D printing
2023-04-18 csv corrected
    [bom.csv]
2023-04-18 assembly first trial
2023-04-20 svg-files via QCAD
    [jamb_broad-w130.dxf, jamb_broad.dxf, jamb_broad_w130.dxf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]
2023-04-21 svg with closed polylines
    [jamb_broad-w130.dxf, jamb_broad.dxf, jamb_broad_w130.dxf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]
2023-04-25 some files renamed
    [jamb_broad.dxf, jamb_broad_qcad.dxf, jamb_jig.dxf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]
2023-05-01 pre-cut-plans again
